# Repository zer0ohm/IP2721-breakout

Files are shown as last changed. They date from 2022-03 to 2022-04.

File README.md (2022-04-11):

# [BETA] IP2721-breakout
Breakout for IP2721 Sink-side USB PD Controller

## Pinout

| Pinname | I/O | Description |
|---|-----|---|
| CC2 | I/O | Type-C Configuration Channel 2 |
| CC1 | I/O | Type-C Configuration Channel 1 |
| SEL | I | VBUS Voltage Select |
| VBG | O | Gate Driver for Load Switch MOSFET |
| VOUT | P | VBUS Output |
| GND | P | Ground |
| TP1/PMG | O | PMOS Gate Pulse Probing Point(Side B only) |

## Usage
Soldering the parts obtained according to the [BOM](./PDBreakout_BOM.pdf) and configure the output voltage of the PD with "SEL_STAT".
* __IMPORTANT: MUST populate 5.1kΩ resistor to CCx, then configure SEL_STAT before power input.__

| SEL_STAT Voltage | Connected Terminals | Output VBUS Voltage |
|---|---|---|
| High | High/H to COM/C | 20V or 12V |
| Float | Do not put jumper | 15V or 9V |
| Low | Low/L to COM/C | 5V |

Note: VBUS voltage is 12/9/5V for IP2721-MAX12

## License
[CC BY-SA 4.0](https://creativecommons.org/licenses/by-sa/4.0/legalcode)

## Disclaimer
There is no warranty, expressed or implied, associated with files in this project. Please use at your own risk.

## Related Document
[IP2721 Datasheet](https://datasheet.lcsc.com/lcsc/2006111335_INJOINIC-IP2721_C603176.pdf)  
[Side A PartMap](./PDBreakout_PartMap_SideA.pdf)  
[Side B PartMap](./PDBreakout_PartMap_SideB.pdf)

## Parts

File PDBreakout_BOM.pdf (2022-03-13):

Item | Reference(s) | Qty | Value | Footprint | MPN | Note | Mounted
1 | C1, C3 | 2 | 2.2uF | 3216Metric | GCM31CR71H225KA55K
2 | C2, C4 | 2 | 10uF | 3216Metric | GRT31CR6YA106KE01K
3 | CN1, CN2 | 2 | UJC-HP-3-SMT-TR | See Datasheet | UJC-HP-3-SMT-TR
4 | CN3, CN4 | 2 | Conn_01x12 | P2.54mm Vertical | 68024-112HLF
5 | D1 | 1 | 1N4148 | SOD-123 | 1N4148W | Side B/PMOS Only
6 | JP1, JP2 | 2 | SEL_STAT | See Datasheet | TSM-103-01-T-SV
7 | Q1 | 1 | DMN4800LSS | SOP-8_P1.27mm | DMN4800LSS
8 | Q2 | 1 | SI4435DY | SOP-8_P1.27mm | SI4435DY | Side B/PMOS Only
9 | Q3 | 1 | IRF7509 | MSOP-8_P0.65mm | IRF7509PbF | Side B/PMOS Only
10 | R1, R2, R3, R4 | 4 | DNP | 1608Metric | ERJ-3GEYJ512V
11 | R5, R6, R7, R8 | 4 | 100kΩ | 1608Metric | SFR03EZPF1003

IP2721-breakout - Bills of materials: Last Update:2022/Mar/13

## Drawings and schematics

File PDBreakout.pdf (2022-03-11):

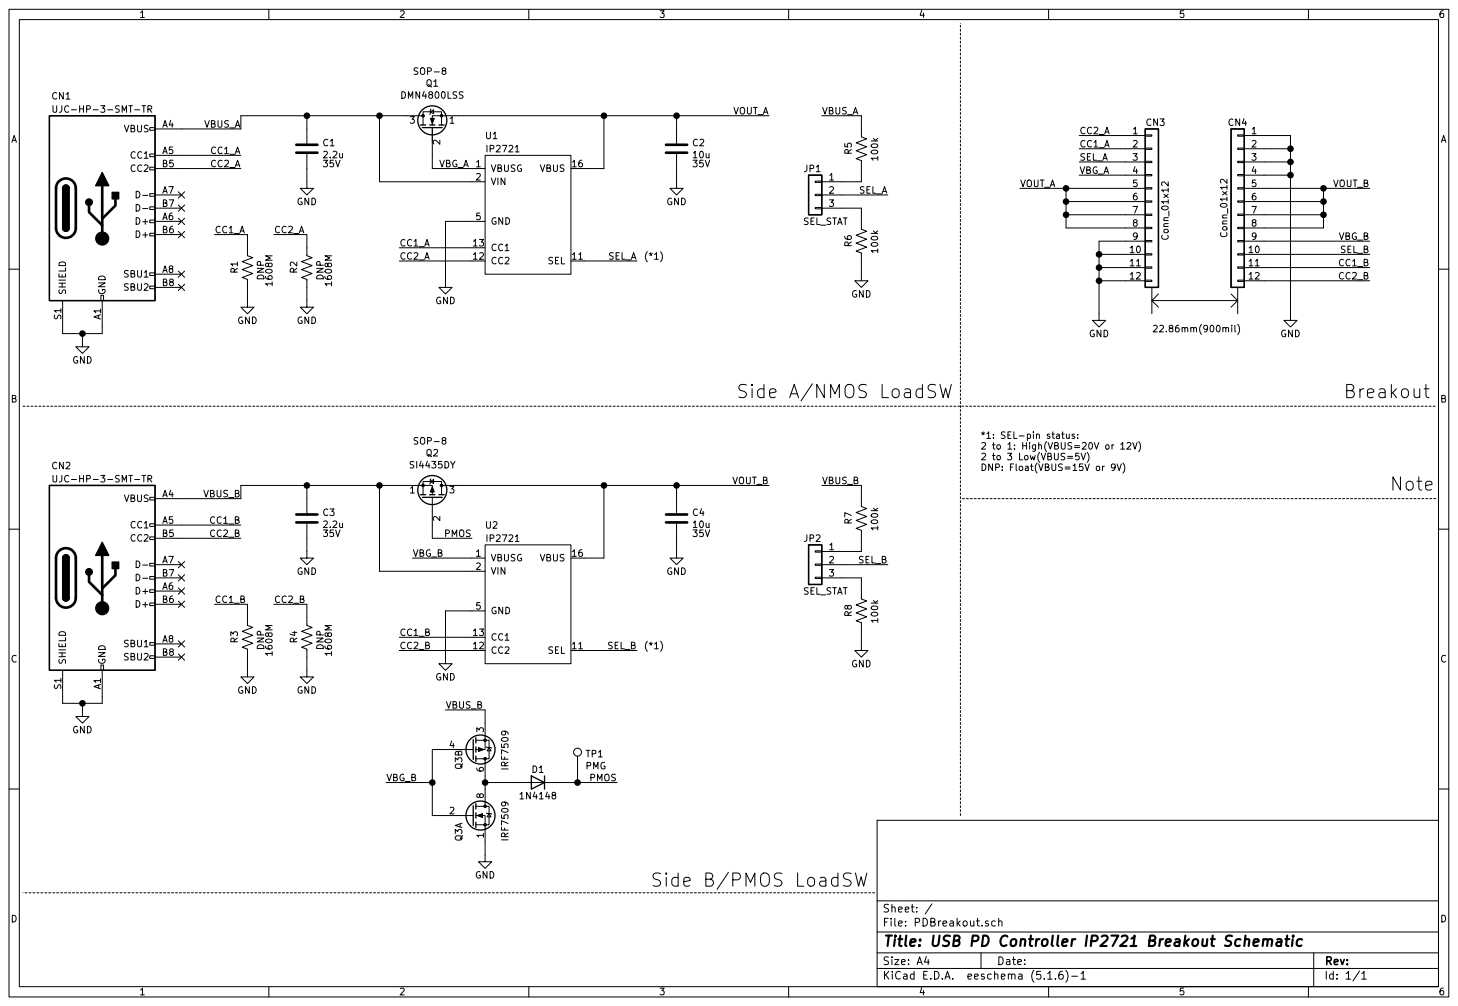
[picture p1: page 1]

*1: SEL-pin status:
2 to 1: High(VBUS=20V or 12V)
2 to 3 Low(VBUS=5V)

Id: 1/1 Title: USB PD Controller IP2721 Breakout Schematic

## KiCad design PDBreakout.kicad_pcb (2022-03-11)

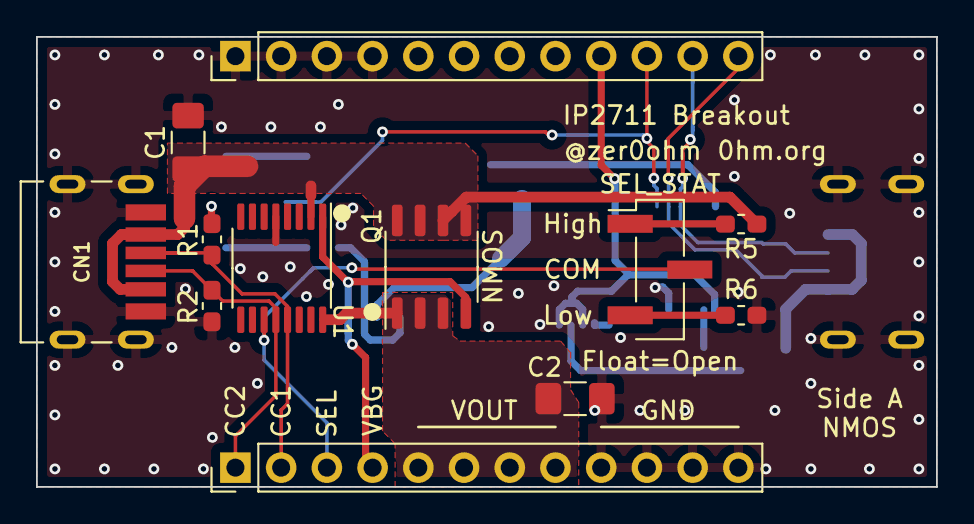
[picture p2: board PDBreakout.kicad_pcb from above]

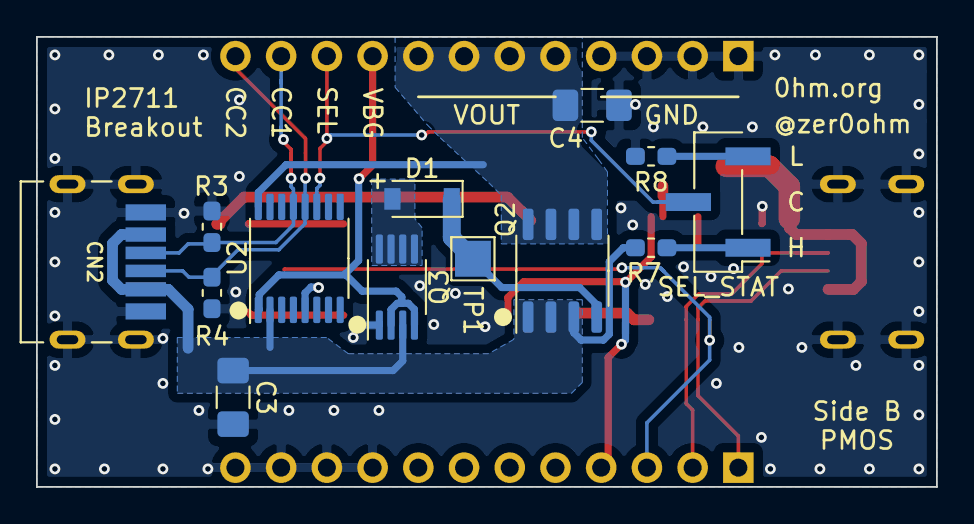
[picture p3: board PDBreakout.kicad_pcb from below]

Board: 2 copper layers, 50.0 x 25.0 mm, 25 parts (13 on the bottom side), 19 nets.

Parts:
C1, C3: 2.2u; C_1206_3216Metric_Pad1.42x1.75mm_HandSolder
C2, C4: 10u; C_1206_3216Metric_Pad1.42x1.75mm_HandSolder
CN1: UJC-HP-3-SMT-TR; CUI_UJC-HP-3-SMT-TR
CN2: UJC-HP-3-SMT-TR; CUI_UJC-HP-3-SMT-TR_HandSoldering
CN3, CN4: Conn_01x12; PinHeader_1x12_P2.54mm_Vertical
D1: 1N4148; D_SOD-123
JP1, JP2: SEL_STAT; PinHeader_1x03_P2.54mm_Vertical_SMD_Pin1Left
Q1: DMN4800LSS; SO-8_3.9x4.9mm_P1.27mm
Q2: SI4435DY; SO-8_3.9x4.9mm_P1.27mm
Q3: IRF7509; MSOP-8_3x3mm_P0.65mm
R1, R2, R3, R4: DNP; R_0603_1608Metric_Pad1.05x0.95mm_HandSolder
R5, R6, R7, R8: 100k; R_0603_1608Metric_Pad1.05x0.95mm_HandSolder
TP1: PMG; TestPoint_Pad_2.0x2.0mm
U1, U2: IP2721; TSSOP-16_4.4x5mm_P0.65mm

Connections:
/CC1_A: CN1.A5, CN3.2, R1.1, U1.13
/CC1_B: CN2.A5, CN4.11, R3.1, U2.13
/CC2_A: CN1.B5, CN3.1, R2.1, U1.12
/CC2_B: CN2.B5, CN4.12, R4.1, U2.12
/PMOS: D1.1, Q2.2, TP1.1
/SEL_A: CN3.3, JP1.2, U1.11
/SEL_B: CN4.10, JP2.2, U2.11
/VBG_A: CN3.4, Q1.2, U1.1
/VBG_B: CN4.9, Q3.2, Q3.4, U2.1
/VBUS_A: C1.1, CN1.B9, Q1.3, R5.1, U1.2
/VBUS_B: C3.1, CN2.B9, Q2.1, Q3.3, R7.1, U2.2
/VOUT_A: C2.1, CN3.5, CN3.6, CN3.7, CN3.8, Q1.1, U1.16
/VOUT_B: C4.1, CN4.5, CN4.6, CN4.7, CN4.8, Q2.3, U2.16
GND: C1.2, C2.2, C3.2, C4.2, CN1.A12, CN1.B12, CN1.S1, CN2.A12, CN2.B12, CN2.S1, CN3.9, CN3.10, CN3.11, CN3.12, CN4.1, CN4.2, CN4.3, CN4.4, Q3.1, R1.2, R2.2, R3.2, R4.2, R6.2, R8.2, U1.5, U2.5
unnamed: D1.2, Q3.5, Q3.6, Q3.7, Q3.8
unnamed: JP1.1, R5.2
unnamed: JP1.3, R6.1
unnamed: JP2.1, R7.2
unnamed: JP2.3, R8.1

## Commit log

2022-03-13 fix bom link
2022-04-11 "Usage"に追記
